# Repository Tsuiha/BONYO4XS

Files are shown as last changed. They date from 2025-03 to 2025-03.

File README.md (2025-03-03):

# BONYO4XS

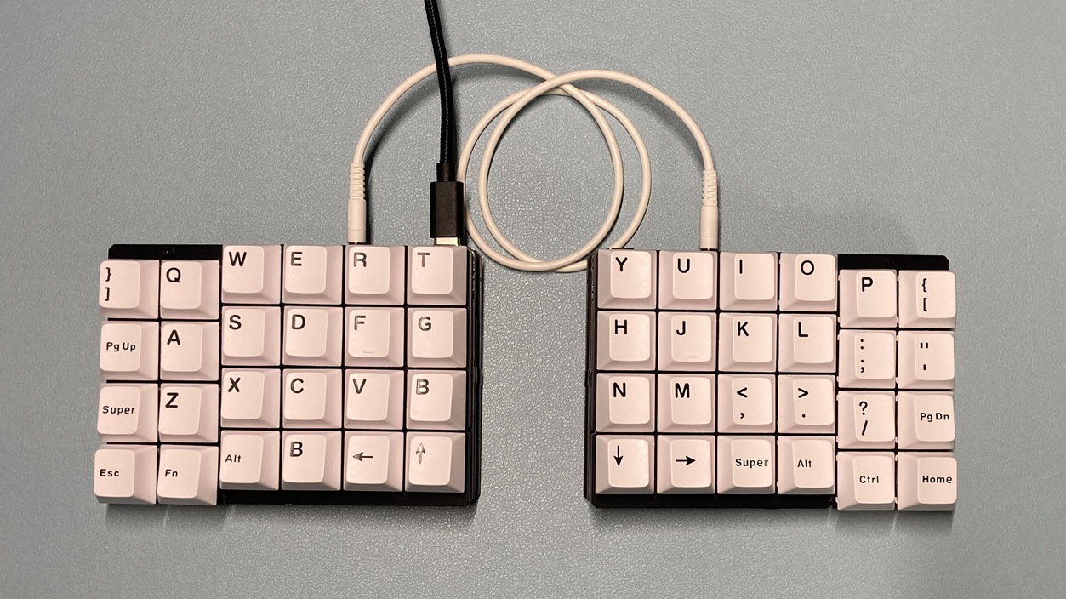
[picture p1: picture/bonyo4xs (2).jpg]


　BONYO4XSは40%サイズの分割キーボードです。
 
　リポジトリに設計データが公開されています。 自由にしてください。

　[noteでも紹介しています](https://note.com/tsuiha/m/m1388ad3cf830)

 片側4x6の計48キーを搭載しているカラムスタッガード（小指列が0.25U下がったオーソリニア）配列です。

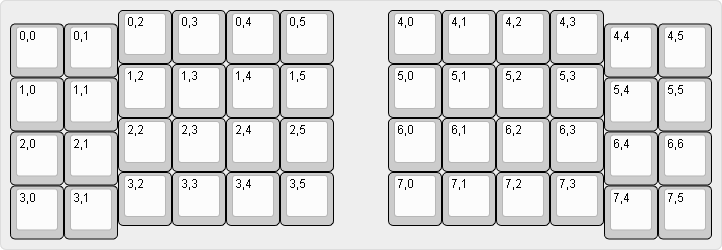
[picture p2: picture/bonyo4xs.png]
 

 　サンドイッチマウント構造で、デフォルト10mm程度のテンティングが施されています。
　奥側のゴム足に高さのあるものを使用することでチルト＋テントの状態で使用することができ、手の姿勢が気持ちよく打鍵できると感じています。

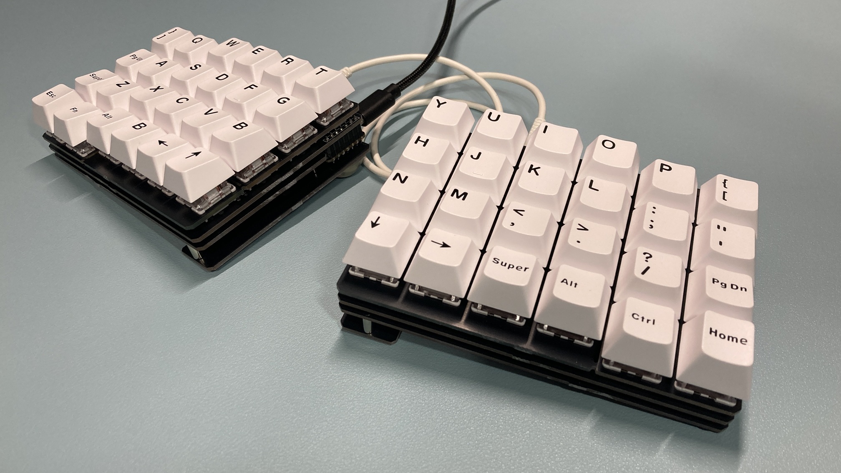
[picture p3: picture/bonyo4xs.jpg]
 

 　親指4キー分のサムクラスタはMXキースイッチだけでなく、プレートを分離することでChoc V2キースイッチにも対応することができます。
  
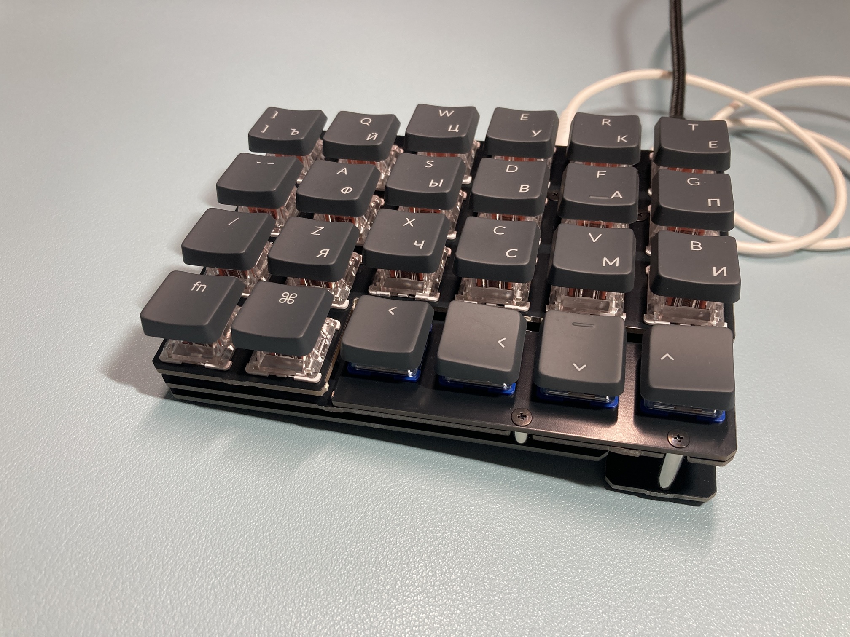
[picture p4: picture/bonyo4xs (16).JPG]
 

 　親指キーにロープロファイルスイッチを使用することで、テンティング時の親指キー高さが気になりにくくなります。

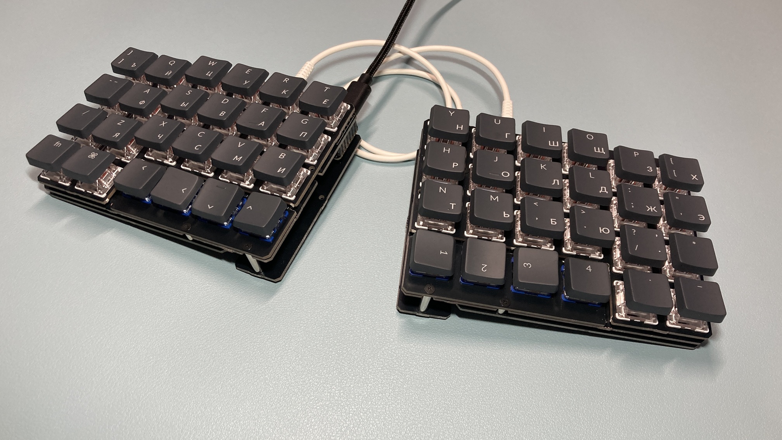
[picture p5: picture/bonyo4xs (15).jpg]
   

   外観写真
   
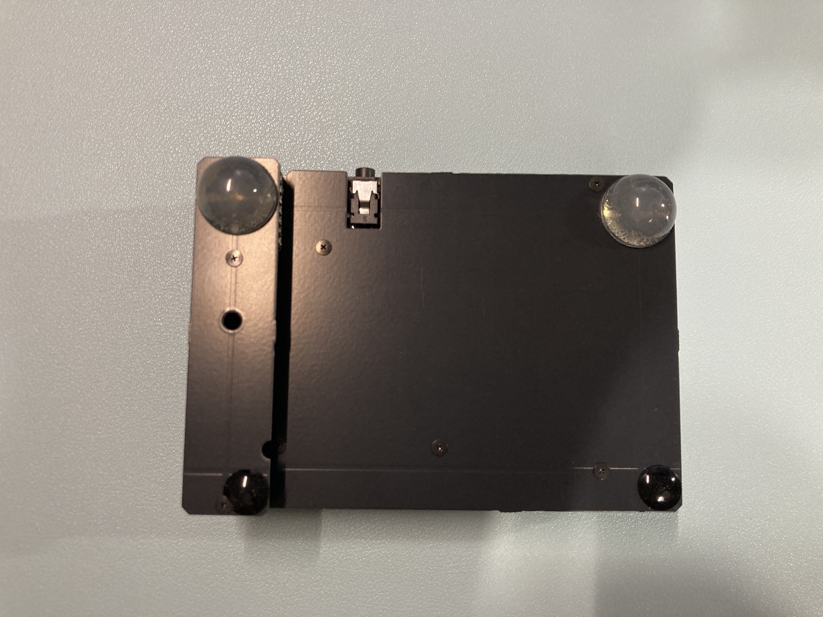
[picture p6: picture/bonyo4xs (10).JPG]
   
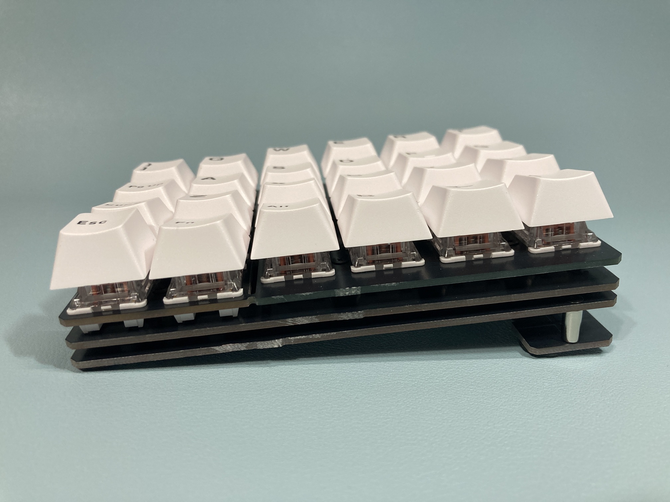
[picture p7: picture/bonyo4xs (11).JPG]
   
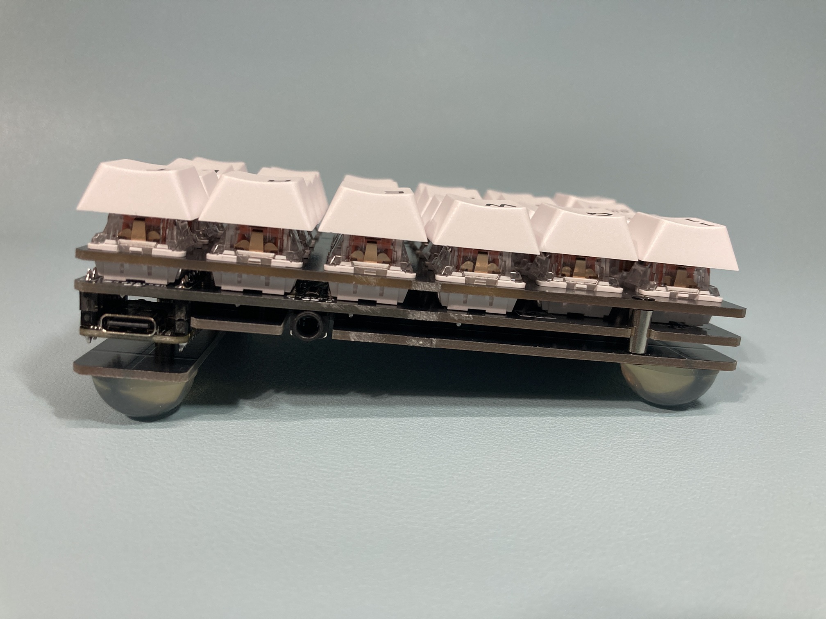
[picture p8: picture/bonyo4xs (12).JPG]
   
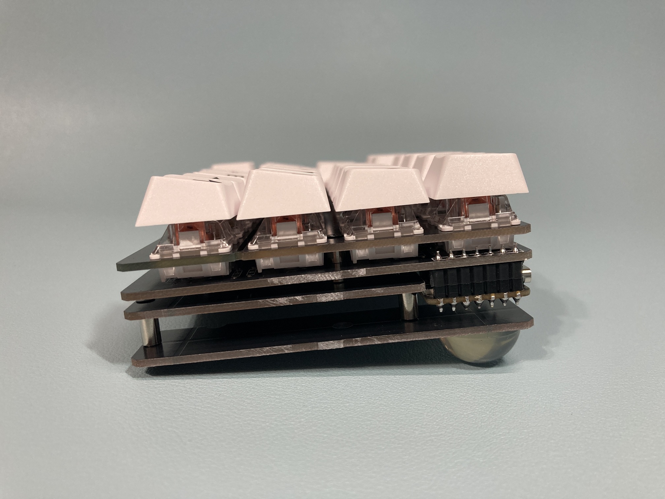
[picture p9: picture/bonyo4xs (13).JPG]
   
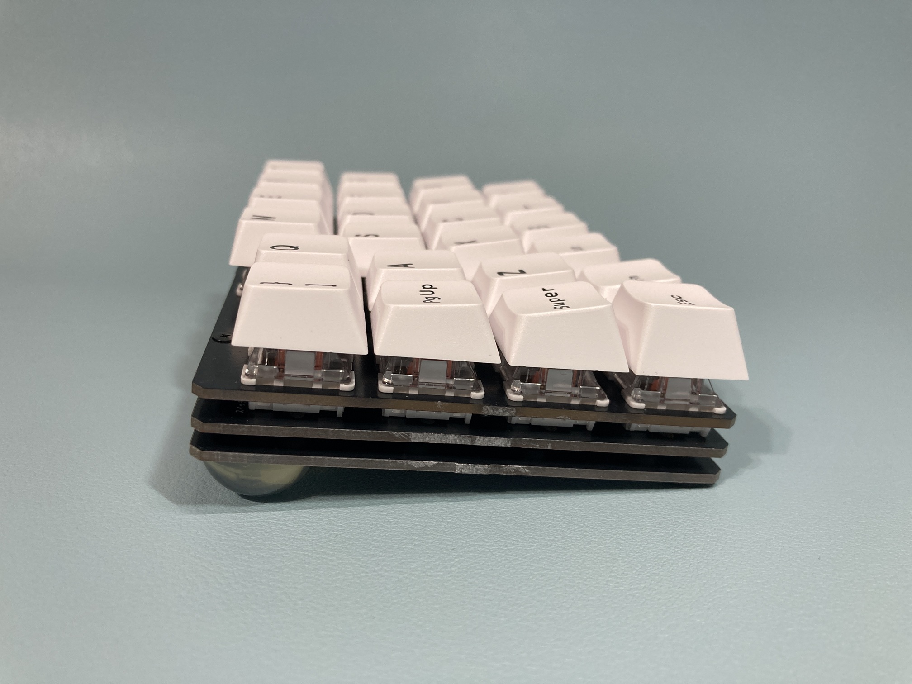
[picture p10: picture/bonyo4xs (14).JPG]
   

   ## ビルドガイド

使用部品はparts listを参照ください。

　実装用基板、スイッチプレート、ボトムプレート、テントプレートの4種が含まれています。
　ラジオペンチ等でランナーを除去し、バリをやすり等で削ります。
 
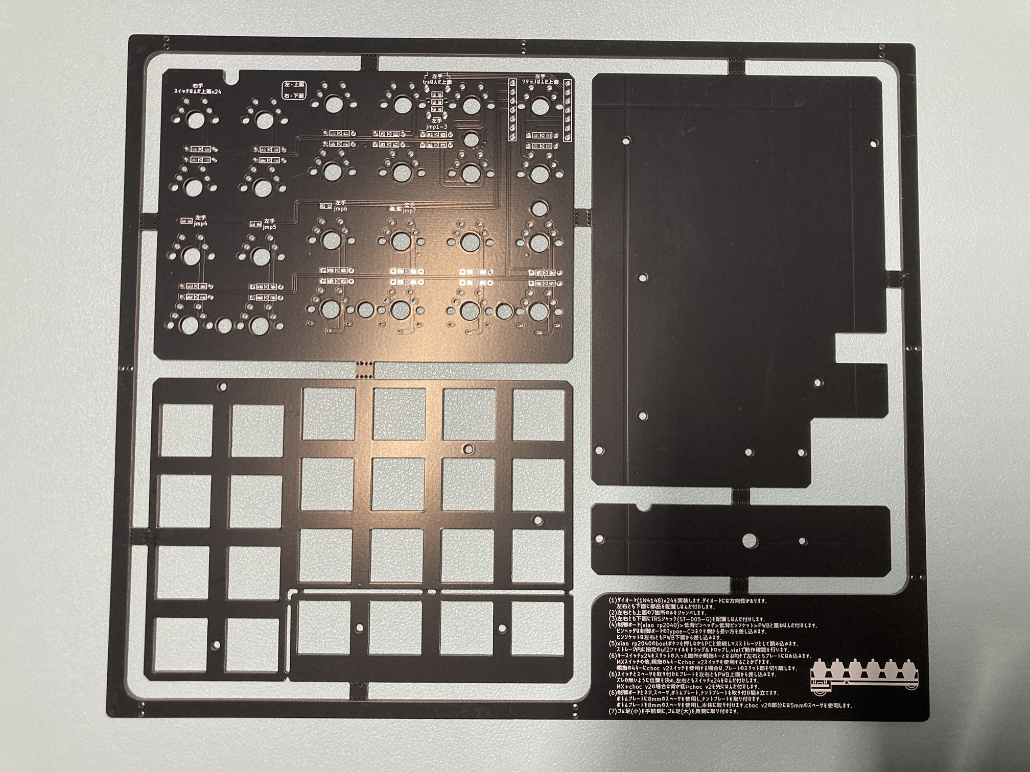
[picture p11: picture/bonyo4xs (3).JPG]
   

　画像を参考に基板に部品を実装します。左右と表裏に注意して進めます。

（下面赤枠）
　ダイオードを24か所に実装します。部品が下面に来るように実装します。画像ではDIPタイプを使用していますが、SMDタイプも使用できます。ダイオードには向きがあります。

（上面赤枠）
　上面の指定7箇所のみをジャンパします。

（下面青枠）
　TRSジャックを部品が下面に来るように実装します。

（下面緑枠）
　ロープロピンソケットを部品が下面に来るように実装します。*マイコンボードと一緒に実装するため、部品実装・マイコンボード項に従ってください。

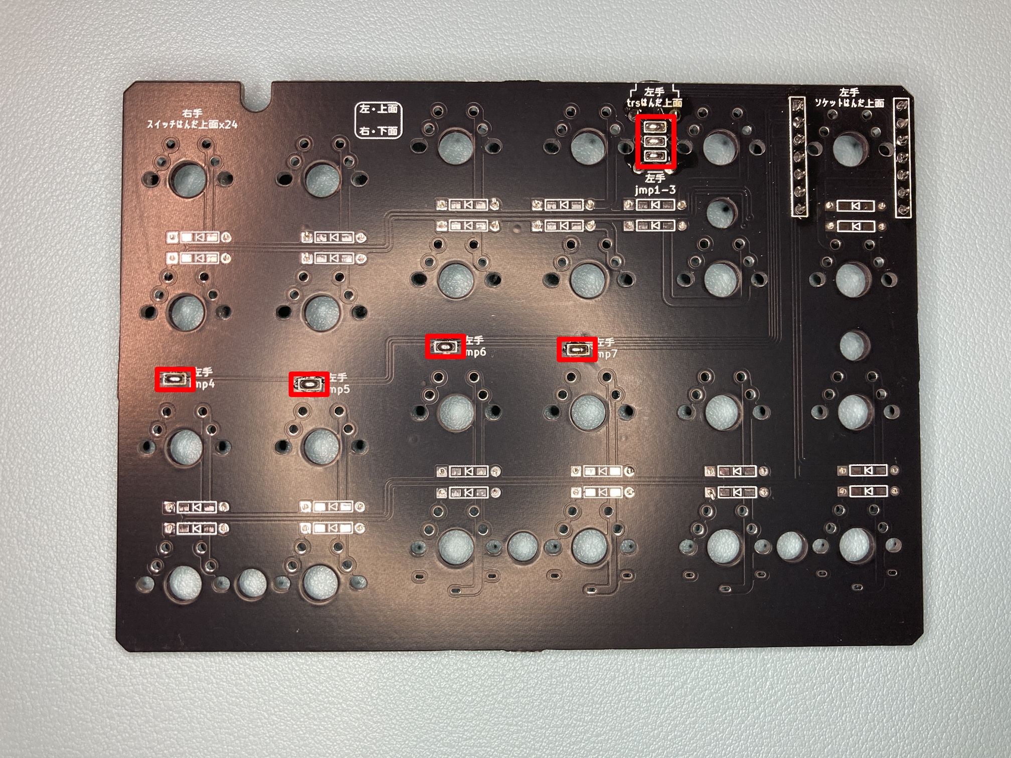
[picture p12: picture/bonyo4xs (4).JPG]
   
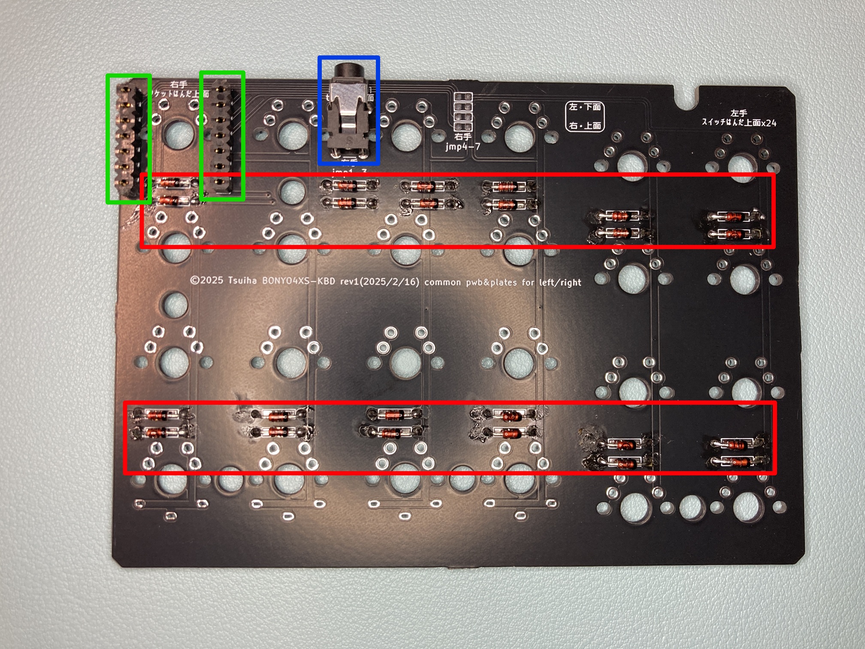
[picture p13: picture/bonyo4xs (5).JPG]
   
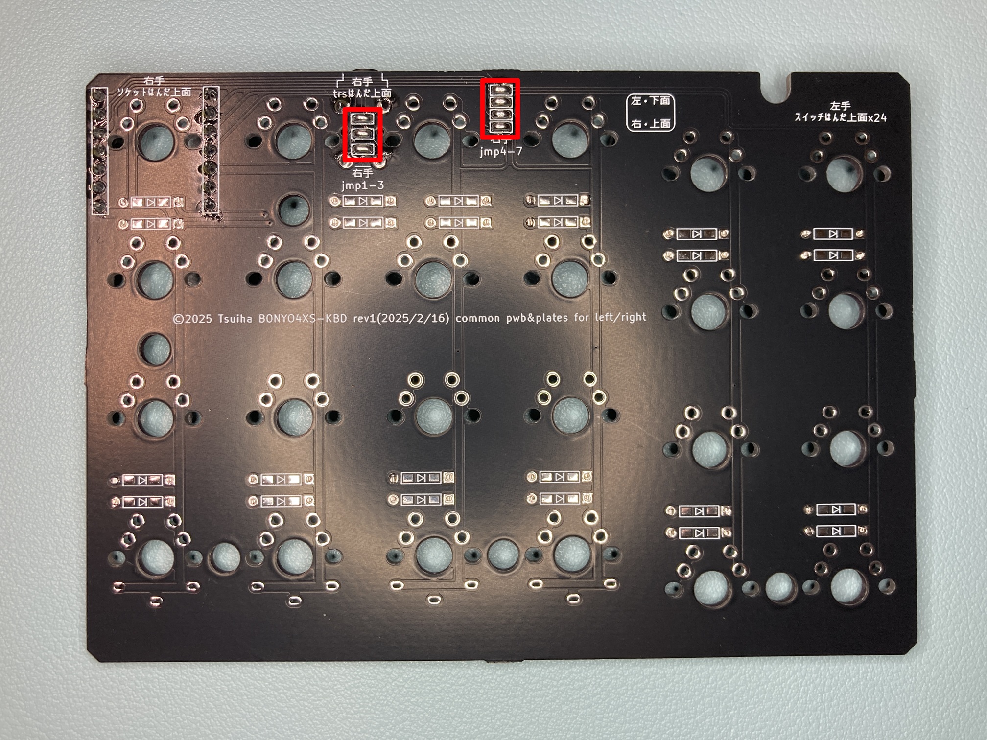
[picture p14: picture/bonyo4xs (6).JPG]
   

部品実装・マイコンボード  
　マイコンボード - ピンヘッダ - ピンソケット - 基板 すべて重ねた状態ではんだ付けを行います。これは後にマイコンボードを容易に取り外せるようにするためです

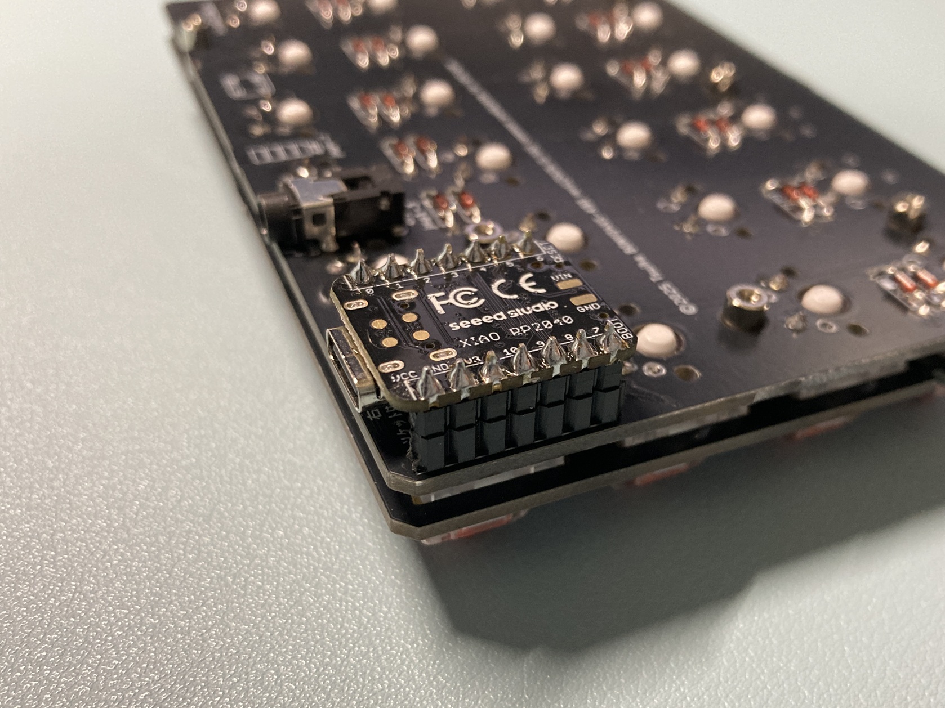
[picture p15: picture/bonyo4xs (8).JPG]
   

部品実装・キースイッチ  
左側を例に進めます。

　スイッチプレートにキースイッチをはめこみます。
　*このときChoc V2を使用する際は、スリット部を切断しChoc V2キースイッチをはめてください。

　8mmスペーサを6か所ねじ止めします。
　*このときChoc V2を使用する際は、親指部に5mmスペーサを使用してください。

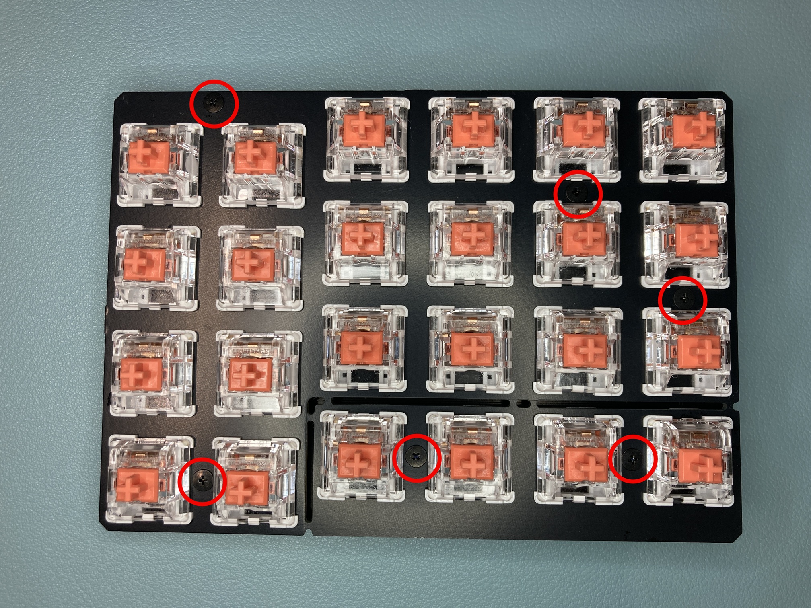
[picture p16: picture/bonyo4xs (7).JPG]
   

ボトムプレートとテントプレートで8mmスペーサを挟み。両側から2か所ねじ止めします。

　マイコンボードを再度基板に装着します。
　基板側とボトムプレート側を重ね、下面から6か所ねじ止めします。

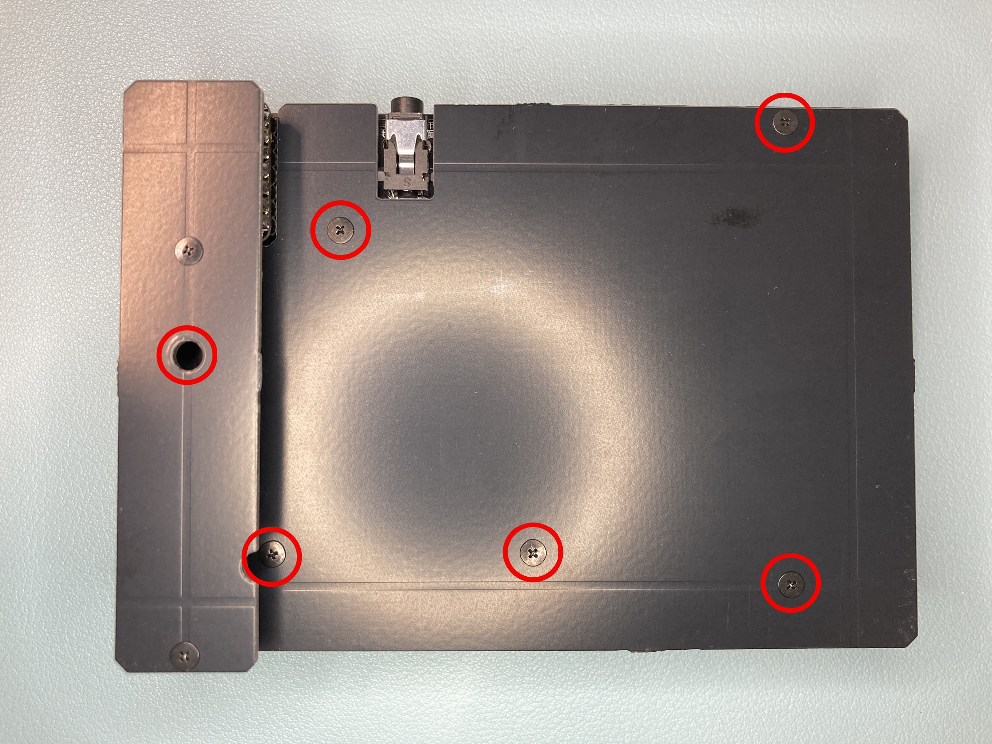
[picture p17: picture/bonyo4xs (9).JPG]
   
   
 完成です。

## qmk-vial
　ファームウェアにはqmk-vialを使用しています。

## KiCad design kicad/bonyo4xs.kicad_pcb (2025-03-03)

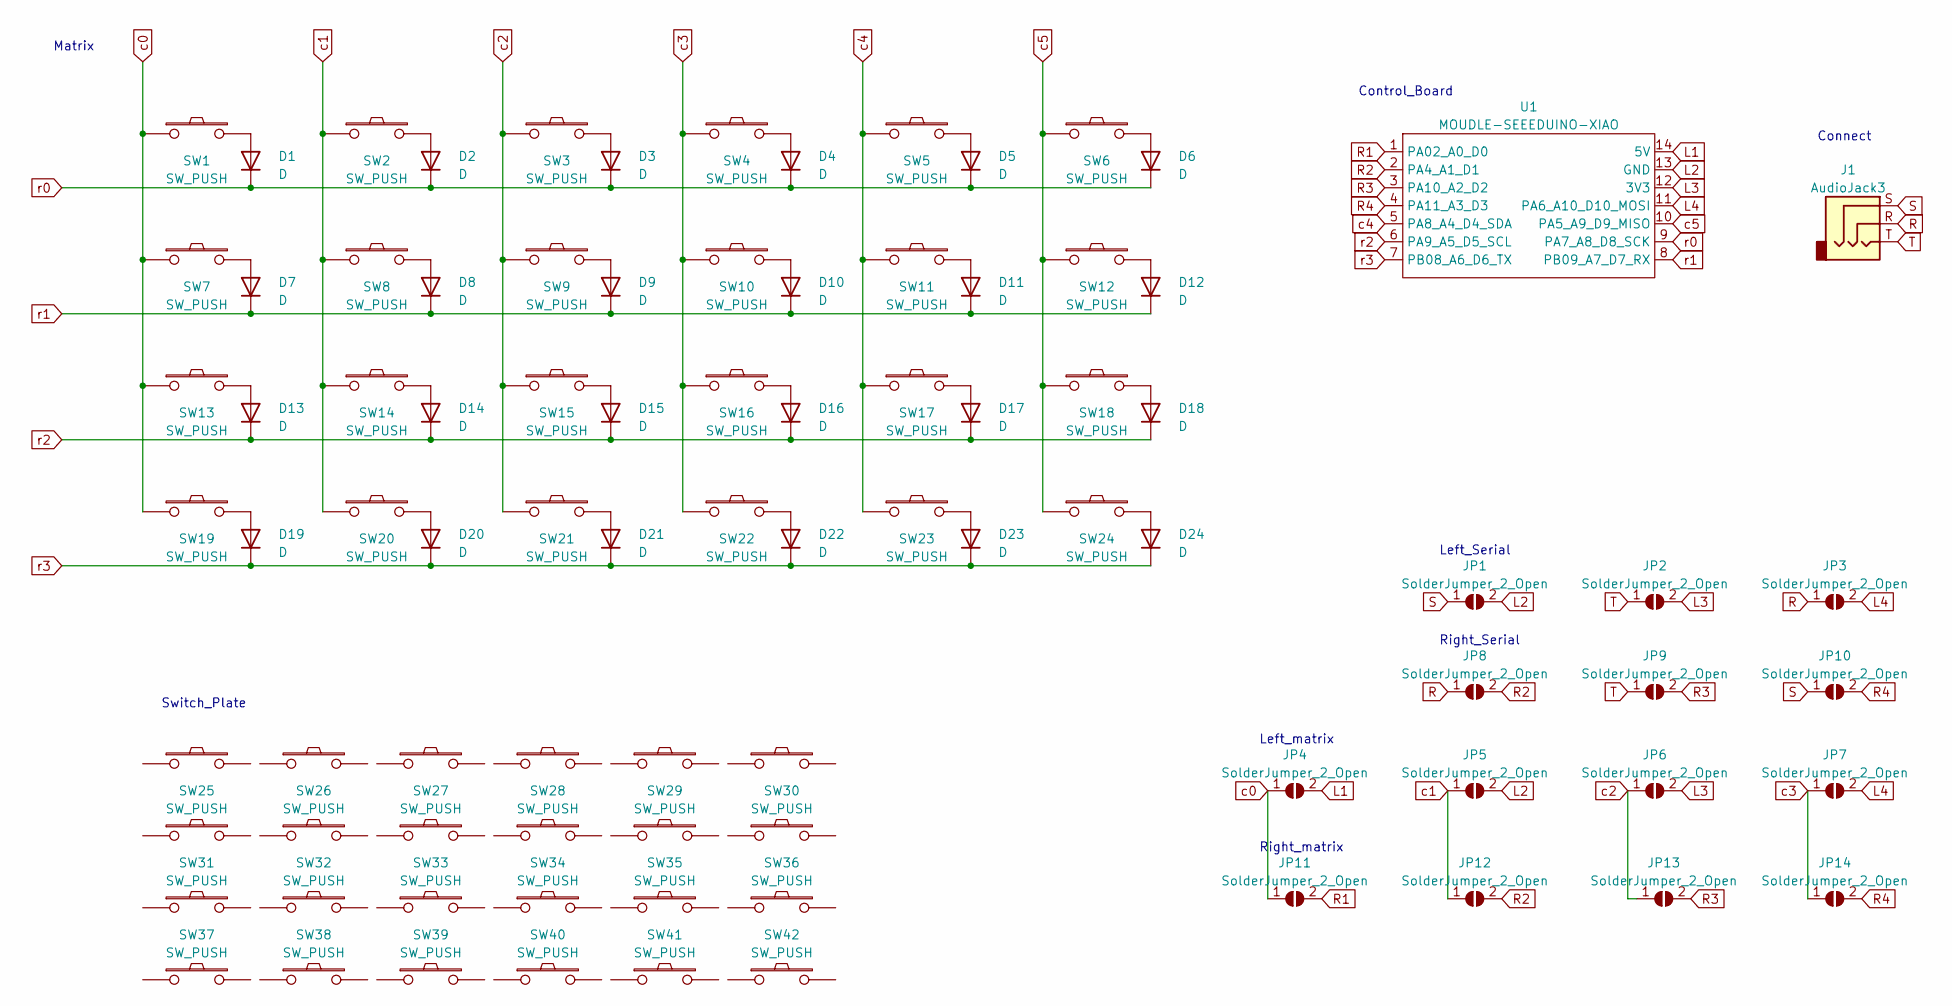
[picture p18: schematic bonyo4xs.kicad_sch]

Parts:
D1, D2, D3, D4, D5, D6, D7, D8, D9, D10, D11, D12, D13, D14, D15, D16, D17, D18, D19, D20, D21, D22, D23, D24: D; D3_TH_SMD
J1: AudioJack3; Jack_3.5mm_Switronic_ST-005-G_horizontal_maru
JP1, JP2, JP3, JP4, JP5, JP6, JP7, JP8, JP9, JP10, JP11, JP12, JP13, JP14: SolderJumper_2_Open; jamp_2
SW1, SW2, SW3, SW4, SW5, SW6, SW7, SW8, SW9, SW10, SW11, SW12, SW13, SW14, SW15, SW16, SW17, SW18, SW19, SW20: SW_PUSH; CherryMX_1u_nofix_rev
SW21, SW22, SW23, SW24: SW_PUSH; CherryMX_ChocV2_1u_nofix
SW25, SW26, SW27, SW28, SW29, SW30, SW31, SW32, SW33, SW34, SW35, SW36, SW37, SW38, SW39, SW40, SW41, SW42, SW43, SW44, SW45, SW46, SW47, SW48: SW_PUSH; SW_Hole_1u
U1: MOUDLE-SEEEDUINO-XIAO; MOUDLE14P-2.54-21X17.8MM

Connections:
L1: JP4.2 (B), U1.14 (5V)
L2: JP1.2 (B), JP5.2 (B), U1.13 (GND)
L3: JP2.2 (B), JP6.2 (B), U1.12 (3V3)
L4: JP3.2 (B), JP7.2 (B), U1.11 (PA6_A10_D10_MOSI)
unnamed: D1.2 (A), SW1.2
unnamed: D2.2 (A), SW2.2
unnamed: D3.2 (A), SW3.2
unnamed: D4.2 (A), SW4.2
unnamed: D5.2 (A), SW5.2
unnamed: D6.2 (A), SW6.2
unnamed: D7.2 (A), SW7.2
unnamed: D8.2 (A), SW8.2
unnamed: D9.2 (A), SW9.2
unnamed: D10.2 (A), SW10.2
unnamed: D11.2 (A), SW11.2
unnamed: D12.2 (A), SW12.2
unnamed: D13.2 (A), SW13.2
unnamed: D14.2 (A), SW14.2
unnamed: D15.2 (A), SW15.2
unnamed: D16.2 (A), SW16.2
unnamed: D17.2 (A), SW17.2
unnamed: D18.2 (A), SW18.2
unnamed: D19.2 (A), SW19.2
unnamed: D20.2 (A), SW20.2
unnamed: D21.2 (A), SW21.2
unnamed: D22.2 (A), SW22.2
unnamed: D23.2 (A), SW23.2
unnamed: D24.2 (A), SW24.2
R: J1.R, JP3.1 (A), JP8.1 (A)
R1: JP11.2 (B), U1.1 (PA02_A0_D0)
R2: JP8.2 (B), JP12.2 (B), U1.2 (PA4_A1_D1)
R3: JP9.2 (B), JP13.2 (B), U1.3 (PA10_A2_D2)
R4: JP10.2 (B), JP14.2 (B), U1.4 (PA11_A3_D3)
S: J1.S, JP1.1 (A), JP10.1 (A)
T: J1.T, JP2.1 (A), JP9.1 (A)
c0: JP4.1 (A), JP11.1 (A), SW1.1, SW7.1, SW13.1, SW19.1
c1: JP5.1 (A), JP12.1 (A), SW2.1, SW8.1, SW14.1, SW20.1
c2: JP6.1 (A), JP13.1 (A), SW3.1, SW9.1, SW15.1, SW21.1
c3: JP7.1 (A), JP14.1 (A), SW4.1, SW10.1, SW16.1, SW22.1
c4: SW5.1, SW11.1, SW17.1, SW23.1, U1.5 (PA8_A4_D4_SDA)
c5: SW6.1, SW12.1, SW18.1, SW24.1, U1.10 (PA5_A9_D9_MISO)
r0: D1.1 (K), D2.1 (K), D3.1 (K), D4.1 (K), D5.1 (K), D6.1 (K), U1.9 (PA7_A8_D8_SCK)
r1: D7.1 (K), D8.1 (K), D9.1 (K), D10.1 (K), D11.1 (K), D12.1 (K), U1.8 (PB09_A7_D7_RX)
r2: D13.1 (K), D14.1 (K), D15.1 (K), D16.1 (K), D17.1 (K), D18.1 (K), U1.6 (PA9_A5_D5_SCL)
r3: D19.1 (K), D20.1 (K), D21.1 (K), D22.1 (K), D23.1 (K), D24.1 (K), U1.7 (PB08_A6_D6_TX)

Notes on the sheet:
Left_Serial
Right_matrix
Left_matrix
Right_Serial
Switch_Plate
Control_Board
Matrix
Connect

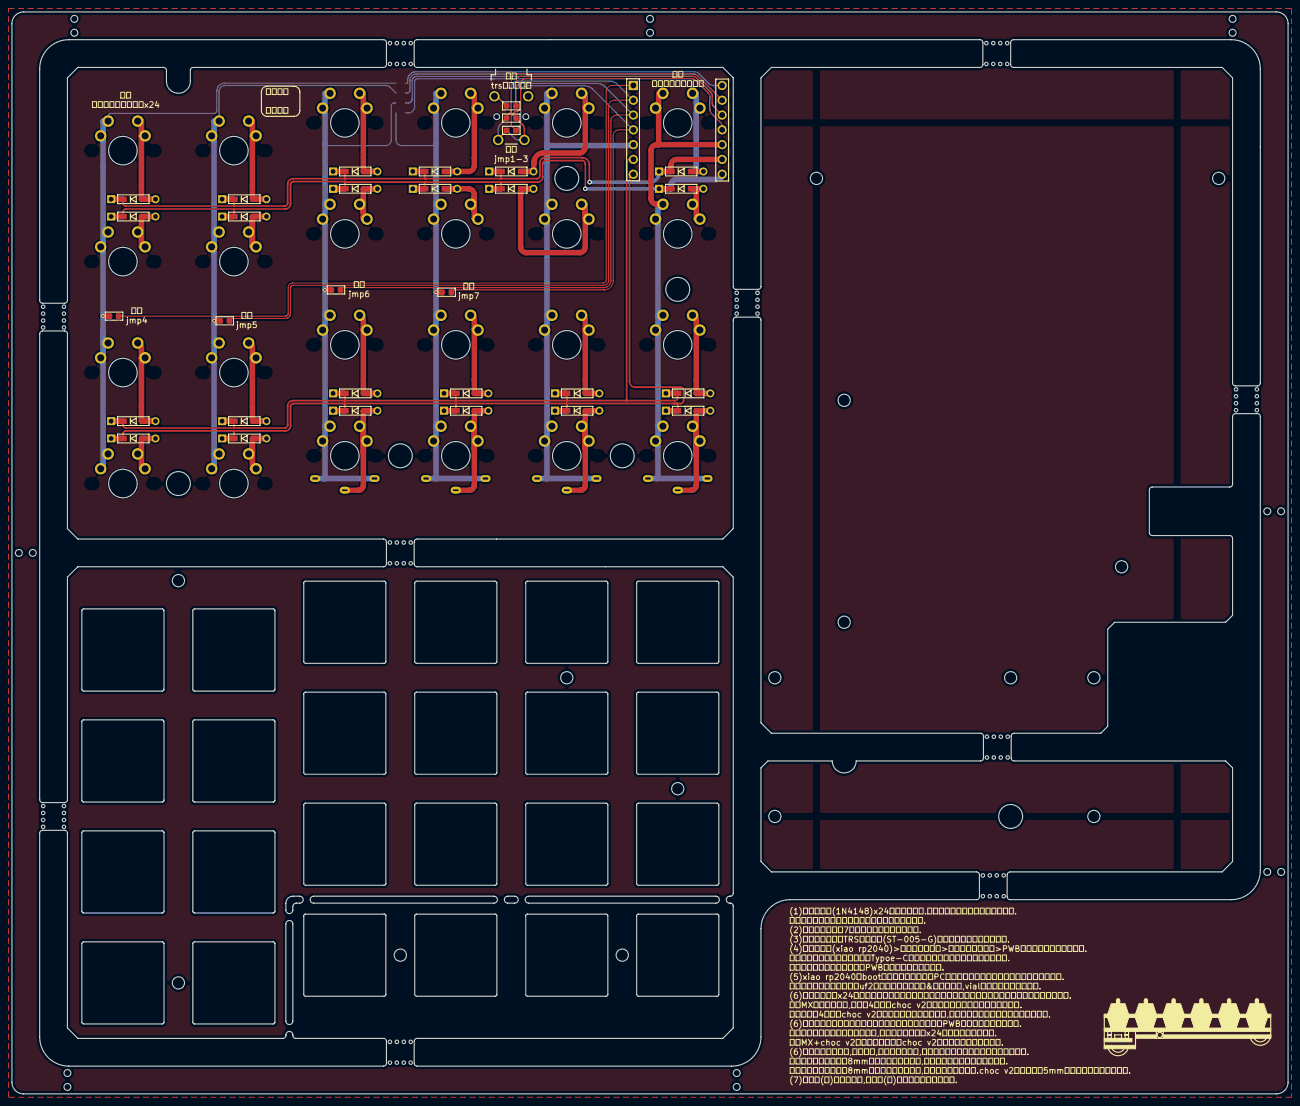
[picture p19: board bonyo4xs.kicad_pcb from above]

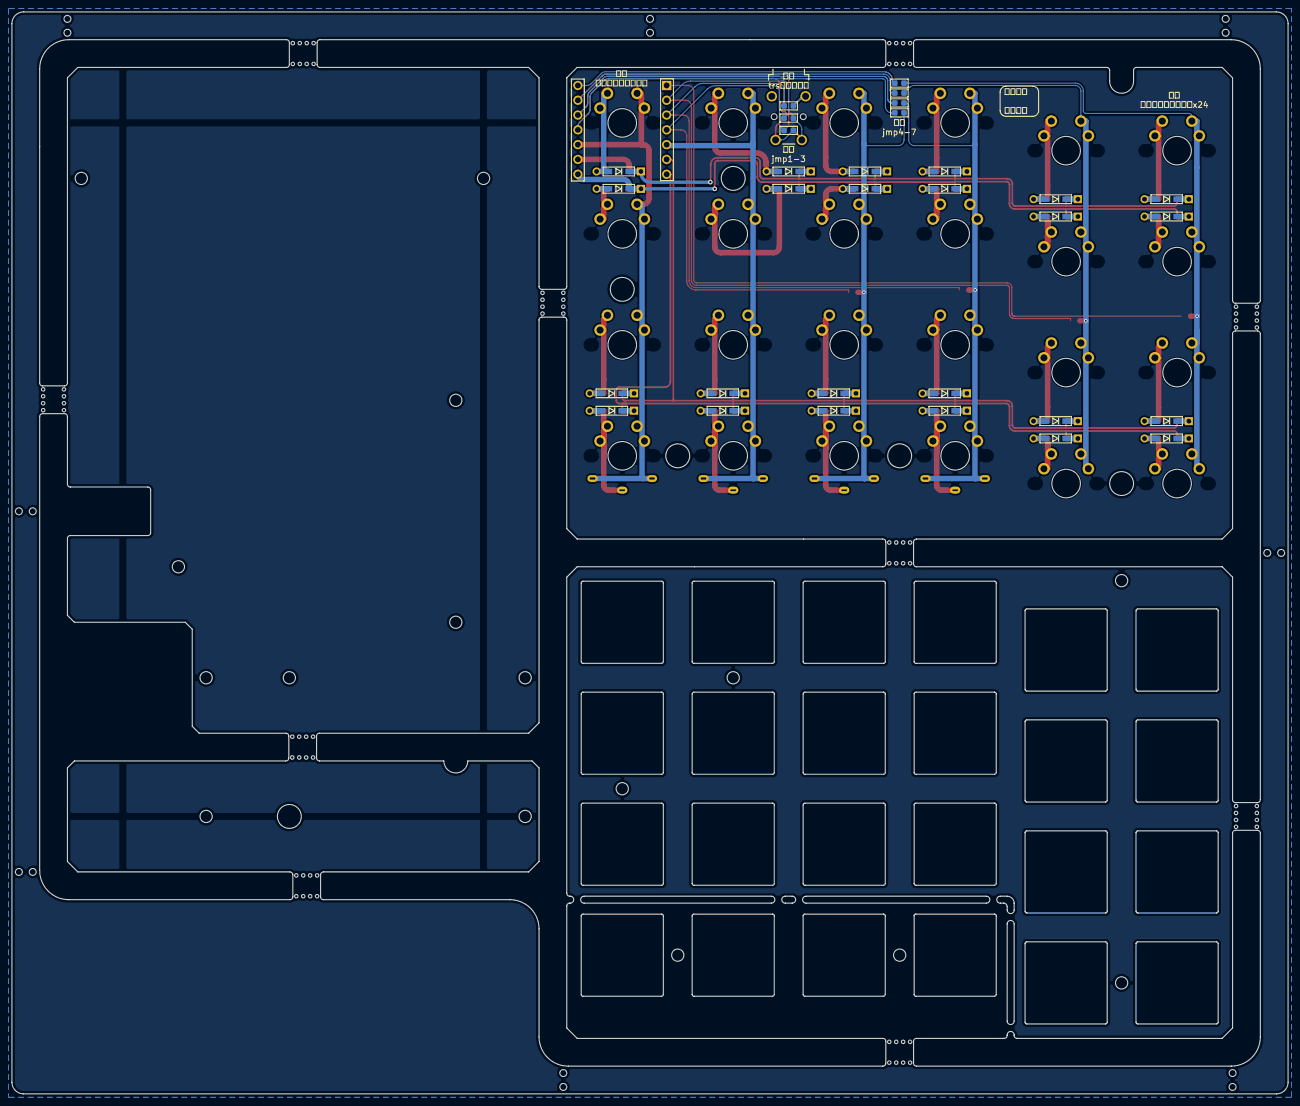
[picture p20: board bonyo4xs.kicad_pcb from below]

Board: 2 copper layers, 219.1 x 185.7 mm, 88 parts (32 on the bottom side), 45 nets.
